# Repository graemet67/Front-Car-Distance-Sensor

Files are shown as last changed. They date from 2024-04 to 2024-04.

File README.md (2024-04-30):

A simple project to add front distance sensors to my car.  My vehicle is a VW Scirroco but mount will also work with MK6 Golf.  Distance is displayed on both the OLED display in cm and via the bar graph - a beeper sounds and display flashes when an object is within 300mm.  Both of these values can be easily changed in the Arduino code.

The list of required parts is in the Wiring and BOM folder.

Note the PCB requires soldering of 0306 SMD resistors.  This can be done with a normal soldering iron but is fiddly.

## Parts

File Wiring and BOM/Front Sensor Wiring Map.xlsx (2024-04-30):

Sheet: Wiring Codes
Screen | Wire | Arduino PIN
SCL | Blue | SCL
SDA | Green | SDA
Bar Graph | Wire | Arduino PIN
GND | BLACK | GND
LED 1 (Red) | RED | D13
LED 2 (Red) | YELLOW | D12
LED 3 (Yellow) | ORANGE | D11
LED 4 (Yellow) | WHITE | D10
LED 5 (Yellow) | PURPLE | D9
LED 6 (Green) | BLUE | D8
LED 7 (Green) | GREEN | D7
LED 8 (Green) | GREY | D6
LED 9 (Green) | BROWN | D5
LED 10 (Green) | WHITE | D4
Ultrasonic Sensor
RX | Green | D0
TX | Blue | D1

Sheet: BOM
Part | Quantity | DFRobot SKU | Price | Total
Arduino R4 Minima | 1 | DFR1085 | 20 | 20
Monochrome 0.91” 128x32 I2C OLED Display | 1 | SKU:DFR0647 | 9.9 | 9.9
Digital Buzzer for Arduino / ESP32 / micro | 1 | DFR0032 | 1.9 | 1.9
A02YYUW Waterproof Ultrasonic Distance Sensor | 1 | SEN0311 | 15.9 | 15.9
5mm x 2 mm LED | 10 |  |  | 10
20R 0805 SMD Resistors | 10 |  |  | 10
M3 x 6mm Allen Key Bolts | 6 |  |  | 6
 |  |  |  | 73.7

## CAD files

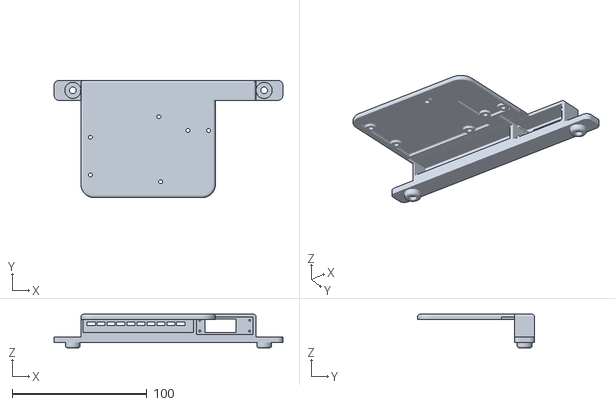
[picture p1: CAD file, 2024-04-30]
3D Printing Files/Sensor Mount (Narrow) with Base v10.stl
170.0 x 87.2 x 25.0

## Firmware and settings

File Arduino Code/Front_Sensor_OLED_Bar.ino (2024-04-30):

#include <Arduino.h>
#include <U8g2lib.h>
#include <Wire.h>
#include <SoftwareSerial.h>

SoftwareSerial mySerial(0,1); // RX, TX
unsigned char data[4]={};
float distance;
const int ledCount = 10;
int displaynum = 0;
int buzzPin =  3; 
int ledPins[] = {
  13, 12, 11, 10, 9, 8, 7 ,6, 5, 4
}; 

U8G2_SSD1306_128X32_UNIVISION_F_HW_I2C u8g2(U8G2_R0, /* reset=*/ U8X8_PIN_NONE);  //M0/ESP32/ESP8266/mega2560/Uno/Leonardo

void setup() {
  for (int thisLed = 0; thisLed < ledCount; thisLed++) {
    pinMode(ledPins[thisLed], OUTPUT);
  } // put your setup code here, to run once:
  pinMode(buzzPin, OUTPUT);
  Serial.begin(57600);
  mySerial.begin(9600); 
  u8g2.begin();
}

void loop() {
 do{
     for(int i=0;i<4;i++)
     {
       data[i]=mySerial.read();
     }
  }while(mySerial.read()==0xff);

  mySerial.flush();
 
 if(data[0]==0xff)
    {
      int sum;
      sum=(data[0]+data[1]+data[2])&0x00FF;
      if(sum==data[3])
      {
        distance=(data[1]<<8)+data[2];
        if(distance>30)
          {          

if(distance < 1200){
int distancecm = distance/10;
  u8g2.clearBuffer();                    
  u8g2.setFont(u8g2_font_logisoso28_tn); 
  u8g2.setCursor(30,30);
  u8g2.print(distancecm); 
  u8g2.sendBuffer();                    
int ledLevel = map(distance, 0, 1450, 0, ledCount);

for (int thisLed = 0; thisLed < ledCount; thisLed++) {

    if (thisLed < ledLevel) {
      digitalWrite(ledPins[thisLed], HIGH);
    } else { // turn off all pins higher than the ledLevel:
      digitalWrite(ledPins[thisLed], LOW);
    }
}
} else {
  u8g2.clearBuffer();                    
  u8g2.setFont(u8g2_font_logisoso28_tr); 
  u8g2.setCursor(30,30);
  u8g2.print("OK");  
  u8g2.sendBuffer();
  for (int thisLed = 0; thisLed < ledCount; thisLed++) {
    digitalWrite(ledPins[thisLed], LOW);
  }

}

            }else 
             {
               Serial.println("Below the lower limit");
             }
      }else Serial.println("ERROR");
     }
 if (distance < 400){
      digitalWrite(buzzPin, HIGH);
     } else {
      digitalWrite(buzzPin, LOW);
     }
delay(100);
}

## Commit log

2024-03-27 Initial Upload
    [Front Sensor Component Base v3.stl, Front Sensor Screen Large v6.stl]
2024-04-29 PCB Design Files Added
    PCB Design Files Added
2024-04-30 Final Versions of All files
    [Front Sensor Component Base v3.stl, Front Sensor Screen Large v6.stl, Front Sensor Wiring Map.xlsx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]
